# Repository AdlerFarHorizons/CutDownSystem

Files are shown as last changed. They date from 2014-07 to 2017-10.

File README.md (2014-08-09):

CutDownSystem
=============

Summary
-------
This is an arduino-based system for separating a high-altitude balloon from its payload under
pre-determined conditions.

Documentation
------------
The documentation available for this system is included in the /docs directory.

Software
--------
In order to run this system, two Arduino boards are required, assembled according to the SCHEMATIC
file. They are pre-programmed; to modify this system, a computer running Arduino IDE is required.
To program the Arduinos, upload new code as specified through the Arduino IDE to the CutDownBase.
The CutDownBase will wirelessly transfer pertinent code to the CutDownRemote.

Licensing
--------
Please see the file named LICENSE.

Contacts
--------

Lou Nigra
Adler Planetarium - Far Horizons Lab

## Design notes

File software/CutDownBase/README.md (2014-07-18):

BaseModule

v3.00 Updated to work with a Copernicus II's GPS readings. This version uses altitude
for its cutdown check, but the position (coordinates) is also available.
SD card logging capability added. Note that GPS connections changed for new software
serial pin assignments for XBee shield SD card compatibility.

v1.10 Updated to avoid conflicts with other Serial messages and added support for
putting the XBee to sleep until near cutdown time.

Brendan Batliner and Milan Shah
Illinois Mathematics and Science Academy - SIR Program

Notes on SD card integration - LN
REF: http://arduino.cc/en/Main/ArduinoWirelessShield
  
  The Wireless shield hardwires Arduino pin 4 to the on-board
  SD card slot's SPI chip select (CS), so it can't be used as
  a Software Serial pin as in the TinyGPS example. Also
  The Arduino's MOSI, MISI and CLK pins (11,12 and 13) are used
  by the SD library and even if not used for SD CS, the default
  CS pin 10 must be programmed as an output.
  
  So, software serial can be assigned to 5 and 6 safely.
  
  TESTING:
  Can be tested without remote cutdown and remote programmer units:
  1. Remove XBee from XBee shield so Arduino USB I/O will work
  2. Provide input via a single monitor line entry emulating the
     remote inputs, for example:
     X90,100000,300,41.1000322,-87.9167100
     This yields: Remote cutdown time (deadman): 90 minutes
                  Cutdown altitude: 100,000 feet
                  Cutdown range: 300 miles
                  Launch Lat/Lon: Koerner Aviation

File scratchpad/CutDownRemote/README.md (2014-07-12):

<h3>CutDownRemote</h3>
<h4>Code for Remote Cutdown Module</h4>
Placed between parachute and ballooon tether, the Remote Cutdown Module cuts connection to the tether when certain conditions are met as determined by the Base Cutdown Module and triggered by wireless sigal. The remote module has a timer pre-set at launch that will trigger the cutdown if other criteria are not met or fail to get a trigger to the remote.

<h4>Revision History</h4>

Placed under CVS at V5.00

V5.00 Adds support for the BaseModule's GPS functions. It will ask
the user about the maximum altitude of the flight and supply this to
the BaseModule.

V3.11 Now No longer Sends the Query 'Q'

V3.01 Now avoids character conflict with base module, to allow the use of a third Xbee to program both the base module and Cutdown arduino

V3.00 Some fixes for high XBee current and workarounds for lack of single point setup control in alpha base station.
- Put XBee to sleep when not needed. Required hardware change.
- Use variable LED flash count to signal ready for input from base allows setup without terminal connection.
- Programming mode until cutter cap is nearly charged.

<h4>Credits</h4>

Lou Nigra
Adler Planetarium - Far Horizons

Brendan Batliner and Milan Shah
Illinois Mathematics and Science Academy - SIR Program

<h4>Controls</h4>

- Raw voltage tied to charger ON switch
- Programming mode when serial port is connected via 3.3V FTDI and XBee removed
- Timer activate/de-activate momentary contact switch (no longer used)

<h4>Indicators</h4>

- LED no blink: Charging => Programming mode inhibited.
- LED fast blink: Active => Timer is counting down.
- LED long Off: Standby => Waiting for programming window to open.
- LED single three flashes: Programming mode => Window open for "non-D"
                            input to enter programming mode.

The following sequence follows if a non-D character is entered while
the window is open:

- LED single six flashes: Parameter prompt: => Ready for parameter entry.
- LED three flashes: Confirmation: => Ready for y or n

<h4>State Machine</h4>
- standby -> WAITFORCHARGE
- WAITFORCHARGE
-   -> GETTTY
- GETTTY
-   (timeout) -> SLEEP
-   (entries) -> active -> SLEEP
- SLEEP
-   standby? > TTY
-   active?  -> timerUpdate

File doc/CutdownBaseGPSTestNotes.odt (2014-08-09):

Cutdown Base/GPS Notes

4/23/14 - Clear Day

Best feedback from GPS when separated from the payload by at least 6 inches, or when left on top of the mini maglite black box inside the payload or at least separated from the cut-down arduino.

Insulation on top of the payload did not appear have any effect on GPS when left separate from the arduino. Results were less consistent when GPS placed on top of the payload cover.

When outside and on top of the payload, best results were on the corners that were furthest from the cut-down arduino.

Also, results seemed to vary depending on which side of the payload the wire protrudes from when GPS is placed on top.

Possible factors for varying results: smaller number of satellites in range (however we have no way of knowing when this is the case, as we do not have a display for that variable) Also the material of the foam insulation of the payload could affect/disturb the RF performance of the device. I will continue tests tomorrow, so as to make sure the results of today are not anomalous.

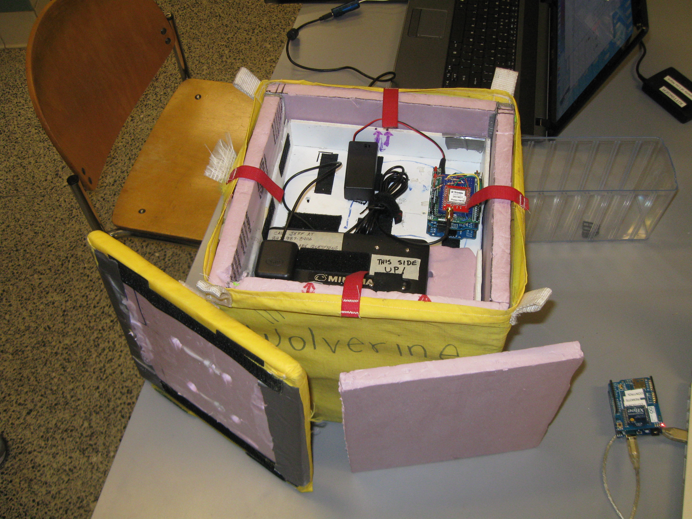
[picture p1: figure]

Illustration 1: Payload with top removed

4/24/14 - Overcast Day

Very poor feedback from GPS when placed anywhere on or in the box.

Best results when GPS receiver placed off of the payload all together, but even then the results are not 100%. May go for a couple of seconds or more before it picks the signal back up.

Tried using just the top of payload and took out extra layer of insulation, seemed to work for a few seconds, then nothing regardless of the corner it was on.

4/29/14 - Mostly Overcast Day

Worked fine with spacer and lid with antenna mounted near corner on maglite case. Also worked at other side of case. Box set on south part of elevator platform with antenna facing antenna doors.

Turned maglite GPS on with spacer removed at 16:28.

Replaced spacer at about 16:31.

Lost data from CutDownBase at 16:34:11 UTC. Not sure if battery died, or just stopped getting fixes.

NOTE: According to the log, the Maglite GPS got no fixes until 10 seconds after CutDownBase GPS stopped getting fixes.

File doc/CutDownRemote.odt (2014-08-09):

CutDownRemote

Lou Nigra
Adler Planetarium – Far Horizons

Rachael Affenit
Illinois Institute of Technology

Kelli W.

Summary:

The CutDownRemote will receive information and new code via Xbee from the CutDownBase. Timer and all other variables can be set remotely via CutDownBase.

The CutDownRemote contains a timer, which can also be changed via the button interface.

When the CutDownRemote capacitors are fully charged (~4.5 volts), charging will cease until charge level has dropped a designated percent below the target value, then resume.

Indicators:

- LED (Charge)
  - Off >> Not yet charged
  - On >> Fully charged
- LED (Timer)
  - Off >> Timer inactive
  - Flashing every 1 second >> Timer active and counting down
- LED (Set Mode)
  - Off >> Not in “Set” Mode
  - On >> Inside “Set” Mode (hold down “Set” switch to deactivate)
- Row of LEDs (Current Variable on Display Lit)
  - Time >> “Timer” LED Lit
  - % Charge on Battery >> “Batt” LED Lit
  - % Charge on Capacitors >> “Cap” LED Lit

Controls:

- Start/Stop Toggle Switch (Timer)
  - Start Timer: Push in switch
  - Stop Timer: Push in and release switch
    - Timer LED turns off
- Set Toggle Switch
  - Enter Set Mode: Push in switch
  - Done Setting Time: Push in and release switch
- Up/Down Momentary Contact Switches (Change time in Set mode)
  - Press up/down buttons to set time
  - Buttons change time by 1 minute in each direction
- Change Variable Momentary Contact Switch
  - Scroll through variables values on display: Press switch (reacts on touch)

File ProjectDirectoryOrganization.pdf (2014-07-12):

## Far Horizons Project Directory Organization

Rev 2.0 August 25, 2013 Lou Nigra
Document Formats
Routine documentation should be in one of the following open formats compatible with free and open source viewers/editors such as OpenOffice, LibreOffice and web browsers, as well as MS Office:

Text-based:
.txt .rtf .docx .html .pdf

Spreadsheet:
.xlsx

Presentation:
.pptx

NOTE ON FILE SIZE:

With figures added to documents, file size can get into the several MB and higher (especially with presentations). Avoid making any document that will be put up in the public domain larger than it has to be. A rough limit might be 1 or 2 MB. You can take forever optimizing this, but just paying attention to it by taking the time to crop and resize images to the actual size needed for real-life viewing can pay off dramatically. Hyperlinks, of course are not a problem.

This DOES NOT apply to internal documents such as presentations (go crazy on those!) and reports. If we publish these to the web after the fact, we can take the time to make a lightweight version appropriate for the web.

The naming of things...

Code Content:
For a given programming language, please google "naming conventions" for code written in that language (e.g., "arduino naming conventions") and try to follow this as best you can in the code. In any case, be self-consistent.

Code Source Files:
Source file names sometimes have conventions as well, but generally not.

Other Files:
For non-code files that you create, the actual name portion of file names should use "CamelCase" convention, where each descriptive word is capitalized rather than separated by spaces or underscores or the like.

After the name part, which should be generic and descriptive, you should add something to distinguish it from other files of the same basic name separating it from the name with a dash. Where that needs further separation, we use underscores. Finally, there's the document suffix that is always separated by a period. That should be the ONLY period.

Every document should have a generic descriptive name and files of the same type should be distinguished from each other by a sequence number, a version number or a date:

a) A simple sequence number: SomeDescriptiveName-34.jpg
b) A version number with two levels (no more, no less): SomeOtherName-V3_12.docx
c) A date: OneReallyAmazingVideo-2013_06_01.mov NOTE: the format is NOT the American “dmy” convention, but the sensible standard the rest of the world uses in its reversed form: yyyy_mm_dd. Add "_ss" if seconds are necessary.
d) A person's initials can be optionally added to any filename: TheBestDesignEver-V943_1_LN.docx

Directories:
Preferably a simple, single-word lowercase name if it's a category like the directories described below. If it has to be more specific, like a directory for a particular program (as with Arduino sketches) then use CamelCase.
The placing of things...

The project directory is organized hierarchically. In the descriptions below, "./" represents the project directory and directories have a trailing "/", while files don't.

./data/
Raw(-ish) data that is large and doesn't have much meaning on its own as documentation, such as raw and high resolution images that need to be kept, files of collected data samples, etc. Organize this into folders if you can and as you see fit.

This directory is will not be tracked on GitHub.

./doc
Documentation that relates to the system design rather than hardware or software design material. An example would might be project design specifications, notes and analysis.

./hardware/
Source files required to re-create and build the hardware design if the project involves hardware design. That would include Eagle schematics and board layouts, mechanical sketches, drawings, etc. The project might include distinct pieces or "modules" that would lend themselves to having separate sub-directories. If there are a lot of files for a single module, you might consider further organizing it into subdirectories such as 'electrical' and 'mechanical' for example.

./hardware/doc/
Hardware-specific design notes, analysis and documentation.

./scratchpad/
This is for any material (programs, schematics, notes, analysis, etc.) that isn't part of the actual design or is still a work in progress. For instance, when you first start on a project, you might try some experimental things to get started or maybe check out some alternative approach to some aspect along the way.

./software/
Source code for any software developed in the project. If there are separate distinct software programs.

.software/doc/

Software-specific design notes, analysis and documentation.

./doc/

Project-level notes, analysis and documentation.

./reference/

Reference material for the project, organized into subdirectories if necessary. This is for things like documents from online sources, designs and code we borrowed from someone else, etc.

The "references.txt" file describes where you got this material. It can also include a description of aother things you used even if there are no associated files, for example, a description/acknowledgment of someone outside of Far Horizons who made a significant contribution. This might have been help with troubleshooting, giving advice or conversations having an impact on the project.

Nothing in this directory except the "references.txt" file should be modified in any way.

./ProjectDirectoryOrganization.pdf

This file.

./README.md

This is visible on the GitHub project page. See the file for a description what should be in it.

./.git/

This is the directory used by git. DO NOT modify it or any of its contents.

./.gitignore

This is a hidden file that tells the git program which directories and file types to ignore in tracking with the GitHub repository. They won't get uploaded to GitHub and are not tracked for changes.

DO NOT edit this file unless you are absolutely sure of what you are doing. Consult with a Far Horizons Engineer if you think files are being suppressed that shouldn't be or if you think some file types or directories should be added to the list.

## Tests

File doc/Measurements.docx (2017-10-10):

The Circuit Layout

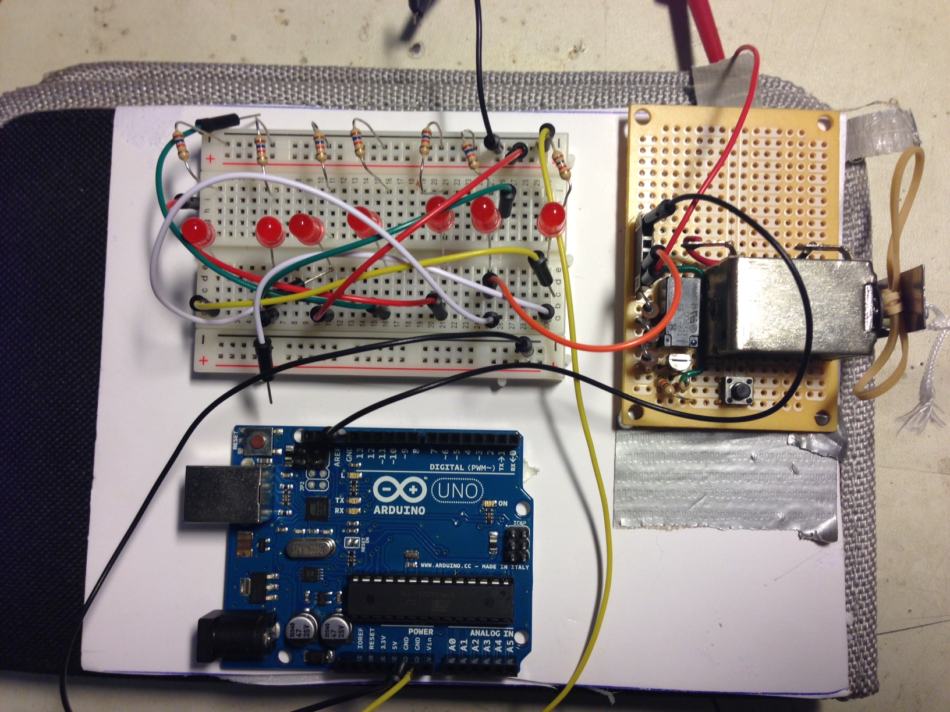
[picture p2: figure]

Some distance displacement for spring in order to get the maximum Force.

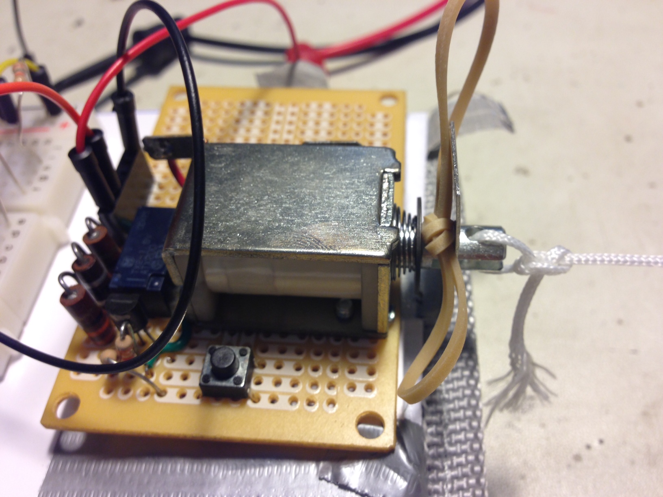
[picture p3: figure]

Experiment Set Up

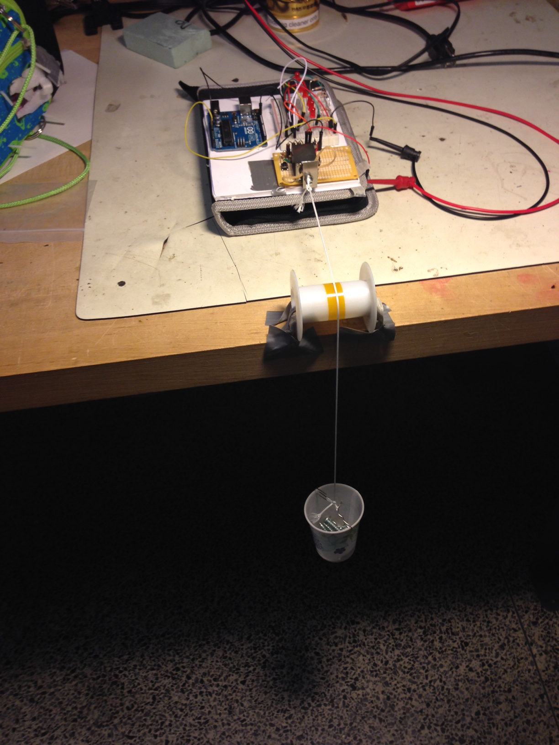
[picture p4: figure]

February 21st, 2015

Today, I have tried to verify experimentally if properties of solenoids F0411A and G0403A correspond to their properties from Data Sheet.

In order to find these properties, I attached weights to the solenoids’ shafts and tested if they could hold the weight. The weights were attached vertically down from the solenoids’ shafts.

The shat itself weights = 8 grams

F0411A – Pontiac Coil (PL012DC) → Continuous

This solenoid has a continuous pull. According to the data sheet, it should have a sealed force of 41 oz., which is 1162 grams.

Experimentally Tested:

1158 g (weight) + 8 g (shaft)= 1166 g → did hold

1174 g (weight) + 8 g (shaft)= 1182 g → did not hold

As a result, experimentally results are very close to those from data sheet specifications.

G0403A – Pontiac Coil → Pulse

According to the data sheet, this solenoid should have a latched force of 37 oz., which is 1049 grams.

Experimentally Tested:

1628 g (weight) +8 g (shaft) = 1636 g → held for 20 seconds and it could more

1702 g (weight) +8 g (shaft) = 1710 g → held for 20 seconds and it could more

1769 g (weight) +8 g (shaft) = 1777 g → held for 18 seconds and it fell down

As a result, the tested results are higher than those from data sheet. Therefore, we might use this solenoid for our upcoming experiment.

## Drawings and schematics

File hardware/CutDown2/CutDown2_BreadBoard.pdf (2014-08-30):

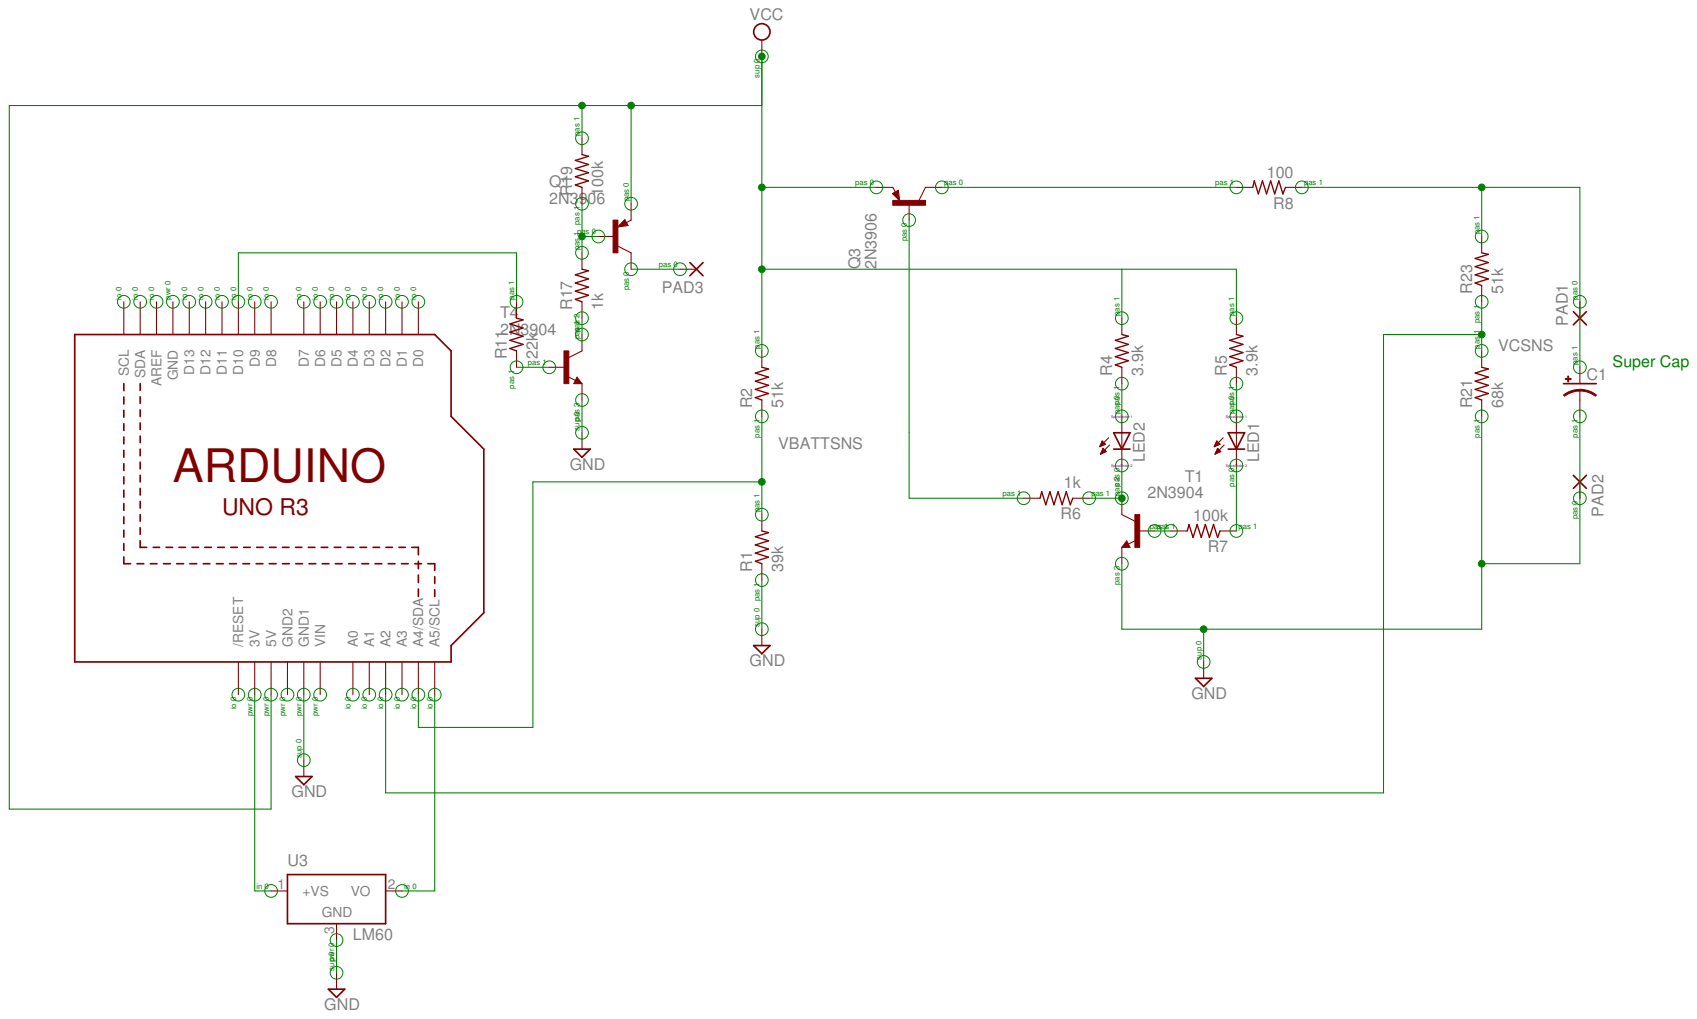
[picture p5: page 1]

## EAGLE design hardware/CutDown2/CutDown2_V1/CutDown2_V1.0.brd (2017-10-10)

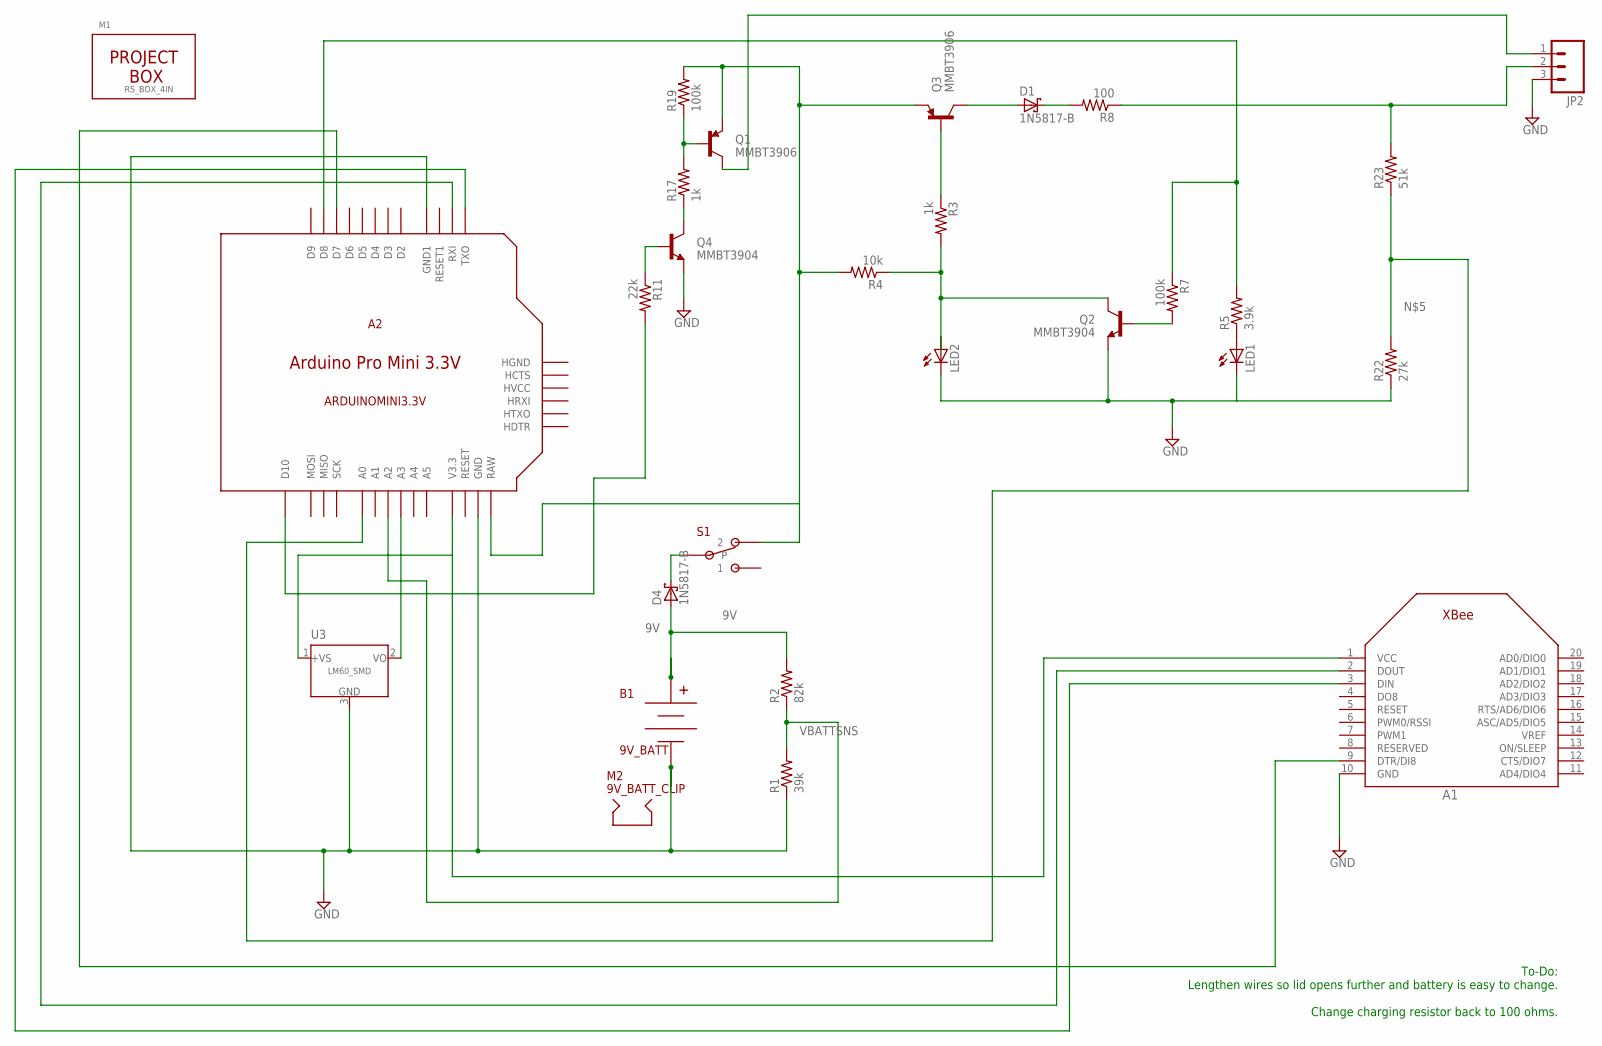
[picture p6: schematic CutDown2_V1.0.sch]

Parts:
A1: XBEE
A2: ARDUINOMINI3.3V
B1: 9V_BATT; KEYSTONE_593_594
D1, D4: 1N5817-B; DO41-7.6
JP2: M03POLAR_LOCK; MOLEX-1X3_LOCK
LED1, LED2: LED_ELD260; LED_LD260
M1: RS_BOX_4IN; RS_BOX_OUTLINE_4IN
M2: 9V_BATT_CLIP; KEYSTONE_9V_CLIP_H
Q1, Q3: MMBT3906; SOT23
Q2, Q4: MMBT3904; SOT23
R1: 39k; R0805
R2: 82k; R0805
R3, R17: 1k; R0805
R4: 10k; R0805
R5: 3.9k; R0805
R7, R19: 100k; R0805
R8: 100; R0805
R11: 22k; R0805
R22: 27k; R0805
R23: 51k; R0805
S1: APEM_SPDT_25000NH
U3: LM60_SMD; SOT23-3

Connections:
9V: B1.P$1 (V+), B1.P$2 (V+), B1.P$3 (V+), D4.A, R2.2
GND: A1.10 (GND), A2.P$9 (GND1), A2.P$20 (GND), B1.P$4 (V-), B1.P$5 (V-), B1.P$6 (V-), JP2.3, LED1.K (C), LED2.K (C), Q2.2 (E), Q4.2 (E), R1.1, R22.1, U3.3 (GND)
unnamed: Q3.1 (B), R3.1
unnamed: D1.A, Q3.3 (C)
unnamed: A2.P$2 (D8), R5.2, R7.1
unnamed: LED1.A, R5.1
unnamed: A2.P$26 (A0), R22.2, R23.1
unnamed: D1.C, R8.2
unnamed: LED2.A, Q2.3 (C), R3.2, R4.1
unnamed: A1.2 (DOUT), A2.P$11 (RXI)
unnamed: A2.P$23 (A3), U3.2 (VO)
unnamed: A1.3 (DIN), A2.P$12 (TXO)
unnamed: D4.C, S1.P$3
unnamed: Q2.1 (B), R7.2
unnamed: Q4.3 (C), R17.1
unnamed: Q1.1 (B), R17.2, R19.1
unnamed: JP2.1, Q1.3 (C)
unnamed: A2.P$30 (D10), R11.2
unnamed: Q4.1 (B), R11.1
unnamed: JP2.2, R8.1, R23.2
unnamed: A2.P$19 (RAW), Q1.2 (E), Q3.2 (E), R4.2, R19.2, S1.P$2 (2)
VBATTSNS: A2.P$24 (A2), R1.2, R2.1
VCC: A1.1 (VCC), A2.P$22 (V3.3), U3.1 (+VS)
VCSNS: A1.9 (DTR/DI8), A2.P$3 (D7)

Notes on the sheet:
To-Do: Lengthen wires so lid opens further and battery is easy to change. Change charging resistor back to 100 ohms.

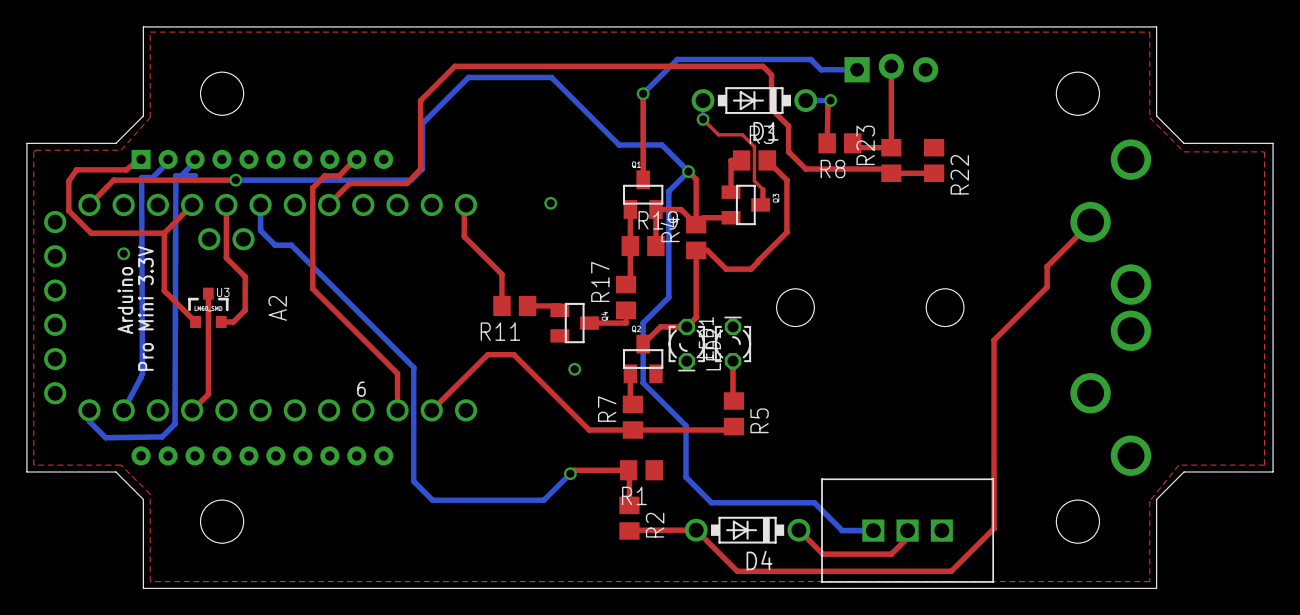
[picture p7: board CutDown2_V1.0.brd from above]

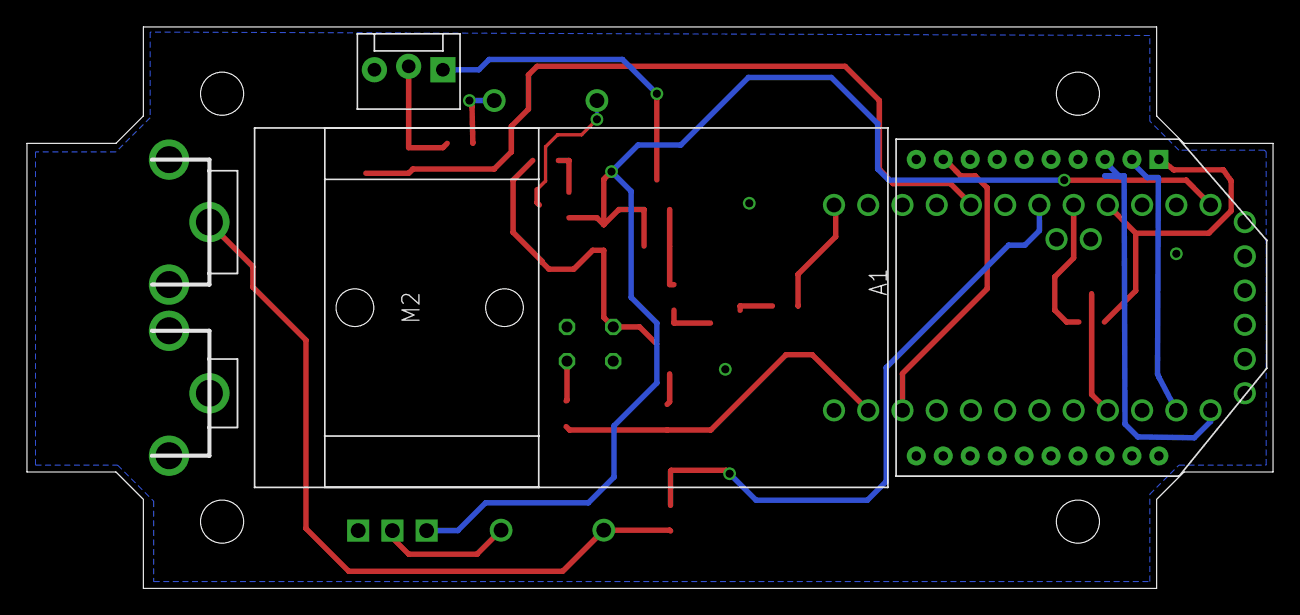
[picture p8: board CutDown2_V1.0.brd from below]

Board: 2 copper layers, 92.5 x 41.7 mm, 28 parts (4 on the bottom side), 24 nets.

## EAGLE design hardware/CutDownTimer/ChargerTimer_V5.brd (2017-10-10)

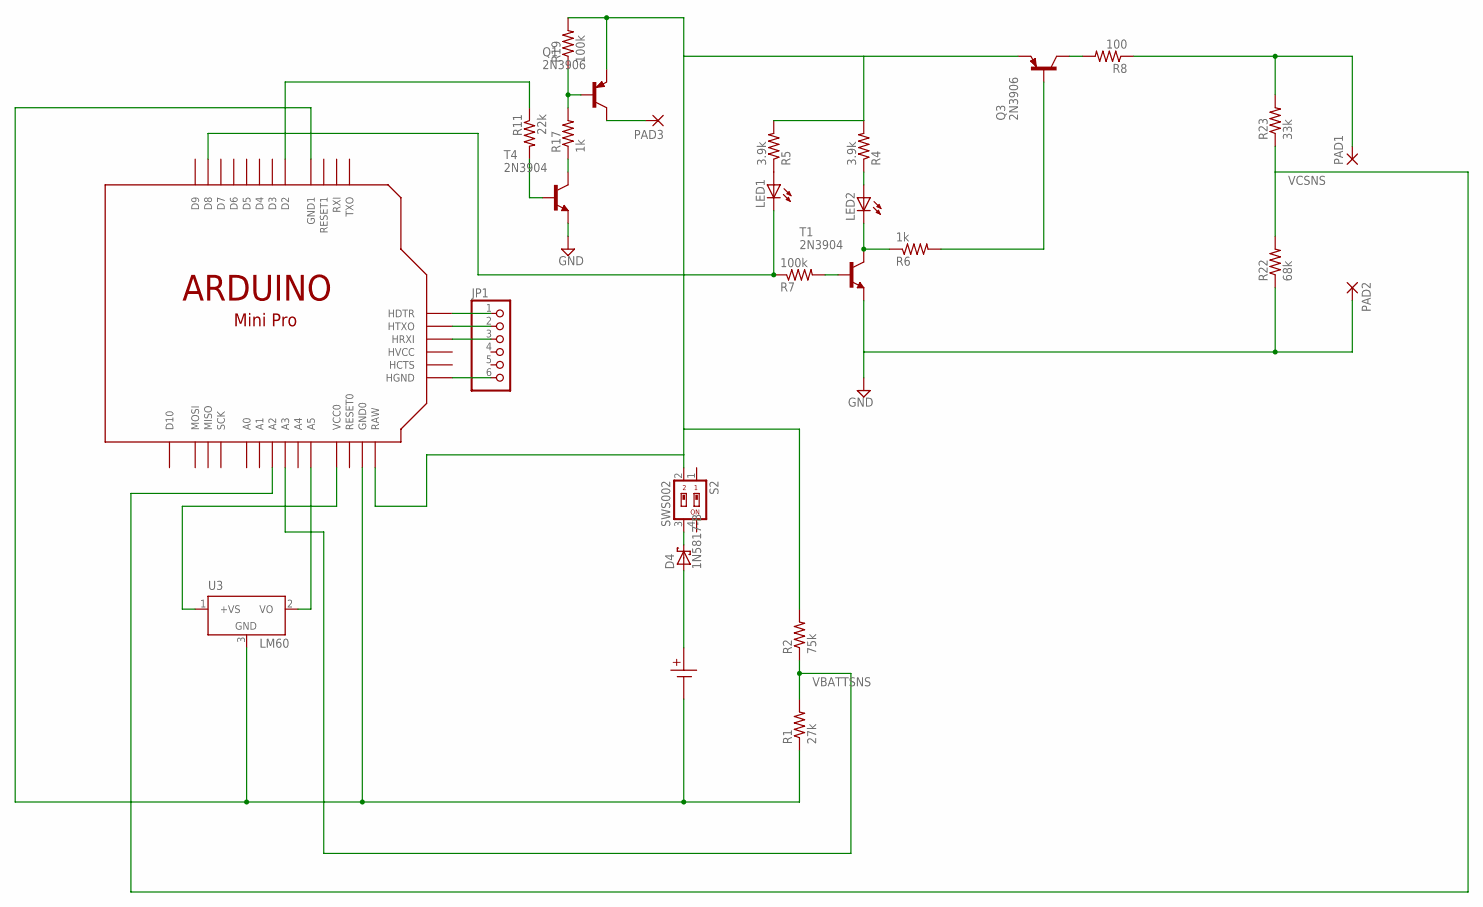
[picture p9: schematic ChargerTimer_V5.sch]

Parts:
D4: 1N5817-B; DO41-7.6
JP1: PINHD-1X6; 1X06
LED1, LED2: LED_ELD260; LED_LD260
PAD1, PAD2, PAD3: 2,15/1,0
Q1, Q3: 2N3906; TO92
R1: 27k; 0207/7
R2: 75k; 0207/7
R4, R5: 3.9k; 0207/7
R6, R17: 1k; 0207/7
R7, R19: 100k; 0207/7
R8: 100; 0207/7
R11: 22k; 0207/7
R22: 68k; 0207/7
R23: 33k; 0207/7
S2: SWS002; SMS-002
T1, T4: 2N3904; TO92
U3: LM60; TO92
U$1: BH1000G
U$4: ARDUINOMINI

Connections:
GND: T1.3 (E), T4.3 (E)
unnamed: Q3.1 (C), R8.2
unnamed: LED1.K (C), R7.1, U$4.P$2 (D8)
unnamed: LED1.A, R5.1
unnamed: LED2.A, R4.1
unnamed: LED2.K (C), R6.1, T1.1 (C)
unnamed: Q3.2 (B), R6.2
unnamed: D4.C, S2.3
unnamed: PAD2.1, R22.1
unnamed: R11.1, U$4.P$8 (D2)
unnamed: Q1.3 (E), Q3.3 (E), R2.2, R4.2, R5.2, R19.2, S2.2, U$4.P$19 (RAW)
unnamed: R7.2, T1.2 (B)
unnamed: R17.1, T4.1 (C)
unnamed: Q1.2 (B), R17.2, R19.1
unnamed: PAD3.1, Q1.1 (C)
unnamed: U3.2 (VO), U$4.P$35 (A5)
unnamed: JP1.1, U$4.P$13 (HDTR)
unnamed: U3.1 (+VS), U$4.P$22 (VCC0)
unnamed: R11.2, T4.2 (B)
unnamed: JP1.2, U$4.P$14 (HTXO)
unnamed: R1.1, U3.3 (GND), U$1.NEG$2 (P2), U$4.P$9 (GND1), U$4.P$20 (GND0)
unnamed: D4.A, U$1.POS$1 (P1)
unnamed: JP1.3, U$4.P$15 (HRXI)
unnamed: JP1.6, U$4.P$18 (HGND)
unnamed: PAD1.1, R8.1, R23.2
VBATTSNS: R1.2, R2.1, U$4.P$23 (A3)
VCSNS: R22.2, R23.1, U$4.P$24 (A2)

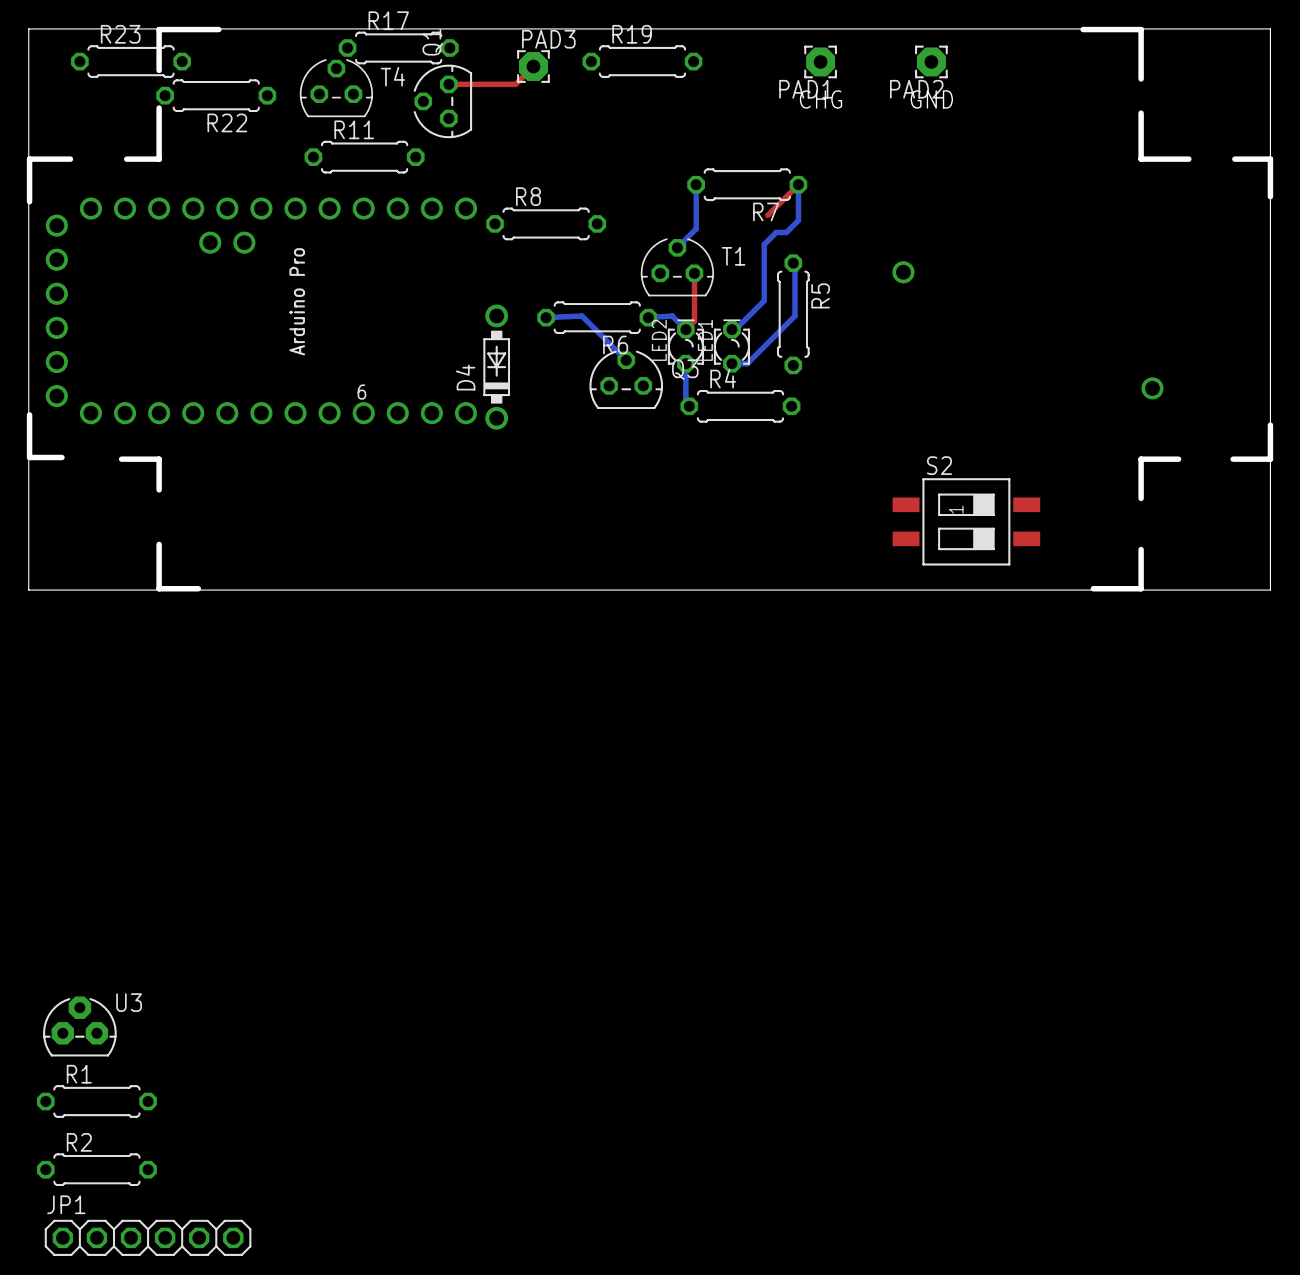
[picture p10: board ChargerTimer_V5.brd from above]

Board: 2 copper layers, 92.5 x 41.8 mm, 27 parts (1 on the bottom side), 27 nets.

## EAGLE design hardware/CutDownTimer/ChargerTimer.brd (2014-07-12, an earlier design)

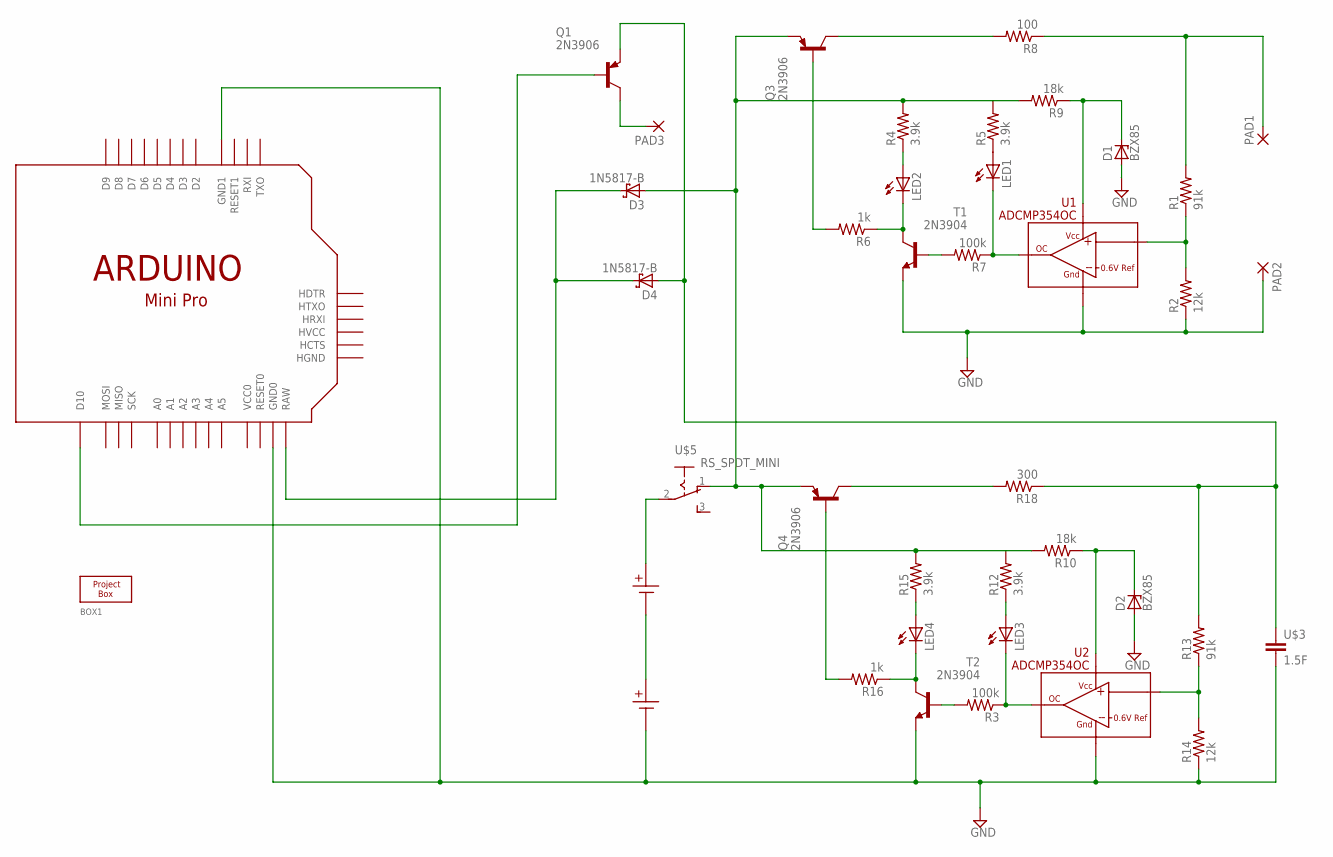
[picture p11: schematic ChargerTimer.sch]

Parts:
BOX1: RS_BOX_4IN; RS_BOX_OUTLINE_4IN
D1, D2: BZX85; DO41Z10
D3, D4: 1N5817-B; DO41-7.6
LED1, LED2, LED3, LED4: LED_ELD260; LED_LD260
PAD1, PAD2, PAD3: 2,15/1,0
Q1, Q3, Q4: 2N3906; TO92
R1, R13: 91k; 0207/7
R2, R14: 12k; 0207/7
R3, R7: 100k; 0207/7
R4, R5, R12, R15: 3.9k; 0207/7
R6, R16: 1k; 0207/7
R8: 100; 0207/7
R9, R10: 18k; 0207/7
R18: 300; 0207/7
T1, T2: 2N3904; TO92
U1, U2: ADCMP354OC; ADCMP35X
U$1, U$2: BH1000G
U$3: 1.5F; SUPERCAP1.0/0.85H
U$4: ARDUINOMINI
U$5: RS_SPDT_MINI

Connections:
GND: D1.A, D2.A, PAD2.1, R2.1, R14.1, T1.3 (E), T2.3 (E), U1.P2 (GND), U2.P2 (GND), U$2.NEG$2 (P2), U$3.P$2 (2), U$4.P$9 (GND1), U$4.P$20 (GND0)
unnamed: R1.1, R2.2, U1.P1 (IN)
unnamed: Q3.1 (C), R8.2
unnamed: LED1.K (C), R7.1, U1.P3 (OUT)
unnamed: LED1.A, R5.1
unnamed: LED2.A, R4.1
unnamed: LED2.K (C), R6.1, T1.1 (C)
unnamed: Q3.2 (B), R6.2
unnamed: PAD1.1, R1.2, R8.1
unnamed: R3.2, T2.2 (B)
unnamed: D4.A, Q1.3 (E), R13.2, R18.1, U$3.P$1 (1)
unnamed: U$1.POS$1 (P1), U$5.2
unnamed: U$1.NEG$2 (P2), U$2.POS$1 (P1)
unnamed: R7.2, T1.2 (B)
unnamed: D1.C, R9.1, U1.P4 (VCC)
unnamed: D2.C, R10.1, U2.P4 (VCC)
unnamed: R13.1, R14.2, U2.P1 (IN)
unnamed: LED3.K (C), R3.1, U2.P3 (OUT)
unnamed: LED3.A, R12.1
unnamed: LED4.A, R15.1
unnamed: LED4.K (C), R16.1, T2.1 (C)
unnamed: Q4.2 (B), R16.2
unnamed: Q4.1 (C), R18.2
unnamed: D3.A, Q3.3 (E), Q4.3 (E), R4.2, R5.2, R9.2, R10.2, R12.2, R15.2, U$5.1 (O)
unnamed: PAD3.1, Q1.1 (C)
unnamed: D3.C, D4.C, U$4.P$19 (RAW)
unnamed: Q1.2 (B), U$4.P$30 (D10)

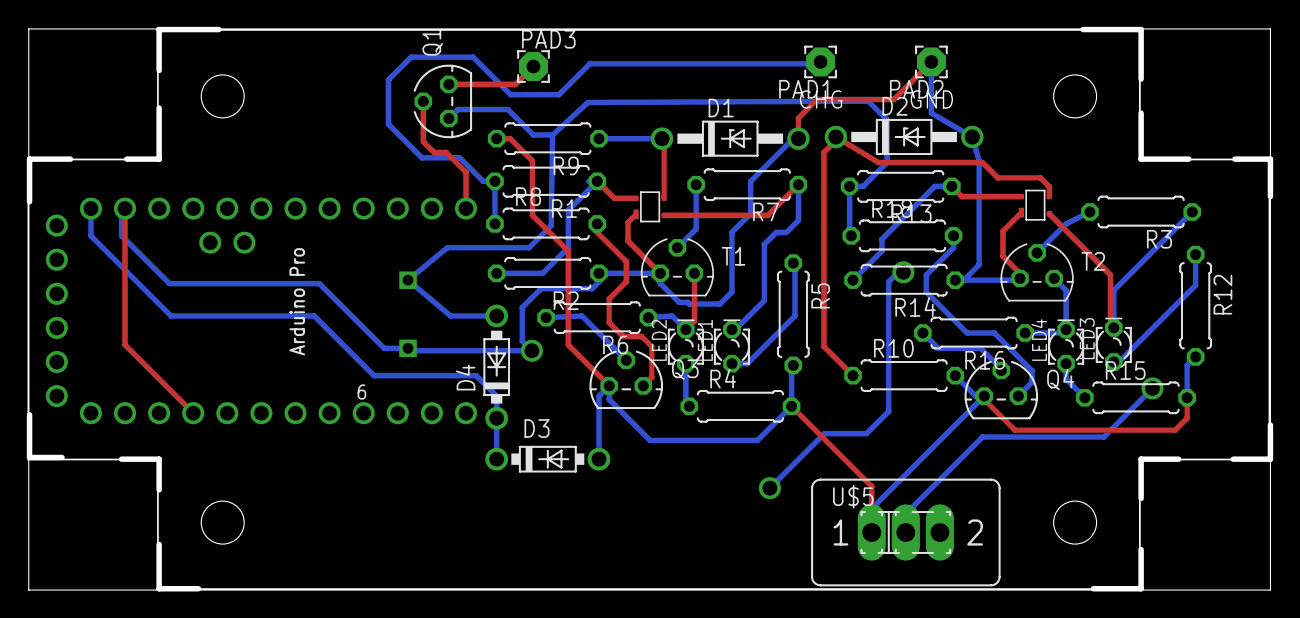
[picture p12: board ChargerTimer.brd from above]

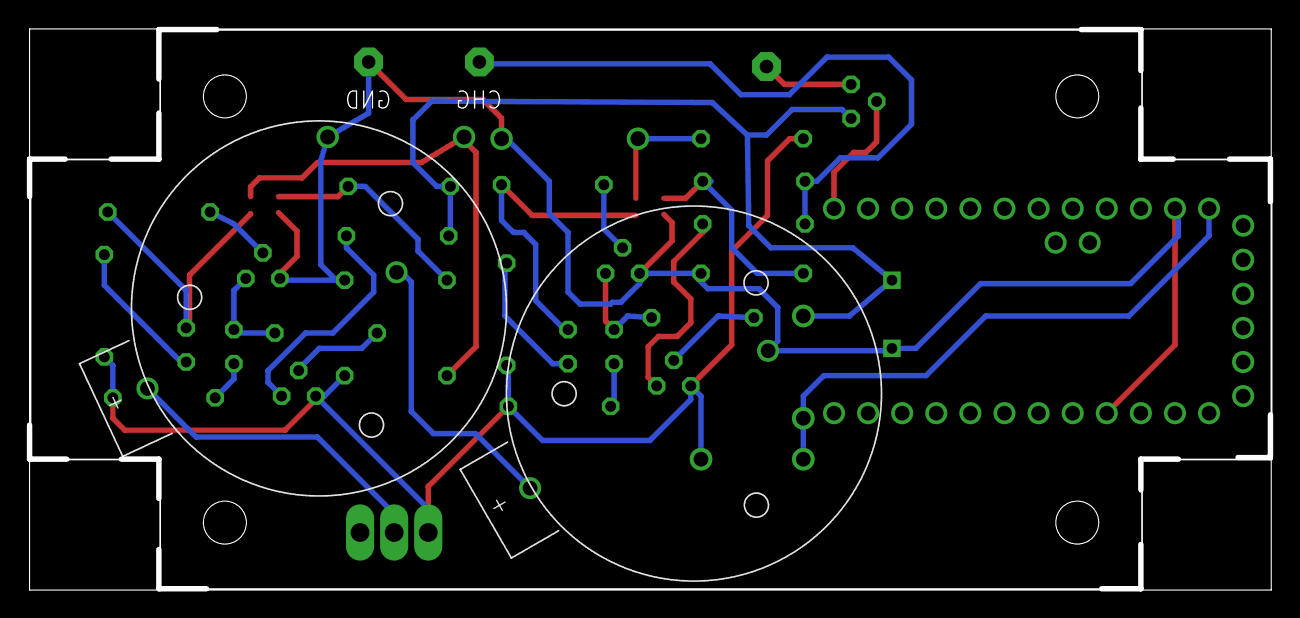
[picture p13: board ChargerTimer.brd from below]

Board: 2 copper layers, 92.5 x 41.8 mm, 40 parts (3 on the bottom side), 27 nets.

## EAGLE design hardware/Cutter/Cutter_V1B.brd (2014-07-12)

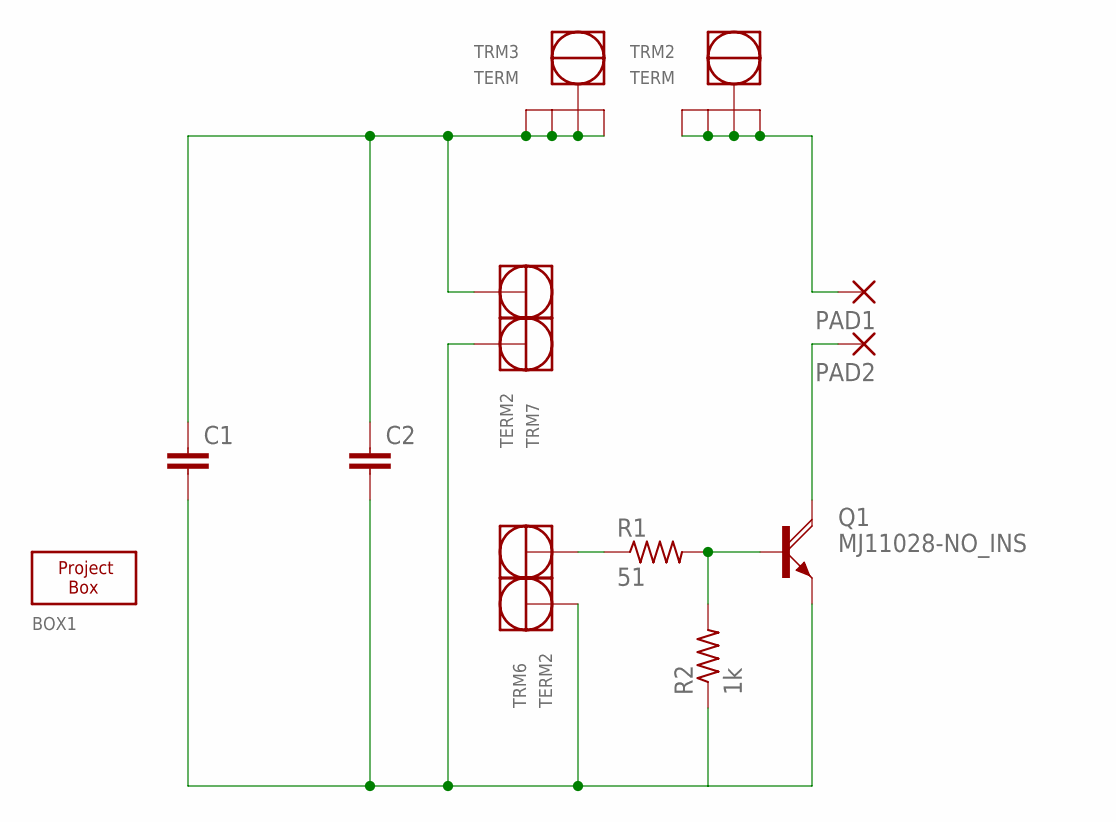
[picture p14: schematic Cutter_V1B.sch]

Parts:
BOX1: RS_BOX_3IN; RS_BOX_OUTLINE_3IN
C1, C2: C1400X850; SUPERCAP1.4/0.85H
PAD1, PAD2: 2,15/1,0
Q1: MJ11028-NO_INS; TO-3-NO_INSULATOR
R1: 51; 0207/10
R2: 1k; 0207/10
TRM2, TRM3: TERM; SCREWTERM-300MILSQ
TRM6, TRM7: TERM2; SCREWTERMBLK-DUAL

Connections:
C: PAD2.1, Q1.C, Q1.C1 (C)
unnamed: C1.P$2 (2), C2.P$2 (2), Q1.E, R2.1, TRM6.P$1 (P1), TRM7.P$1 (P1)
unnamed: C1.P$1 (1), C2.P$1 (1), TRM3.P$1 (P1), TRM3.P$2 (P2), TRM3.P$3 (P3), TRM3.P$4 (P4), TRM7.P$2 (P2)
unnamed: PAD1.1, TRM2.P$1 (P1), TRM2.P$2 (P2), TRM2.P$3 (P3), TRM2.P$4 (P4)
unnamed: Q1.B, R1.2, R2.2
unnamed: R1.1, TRM6.P$2 (P2)

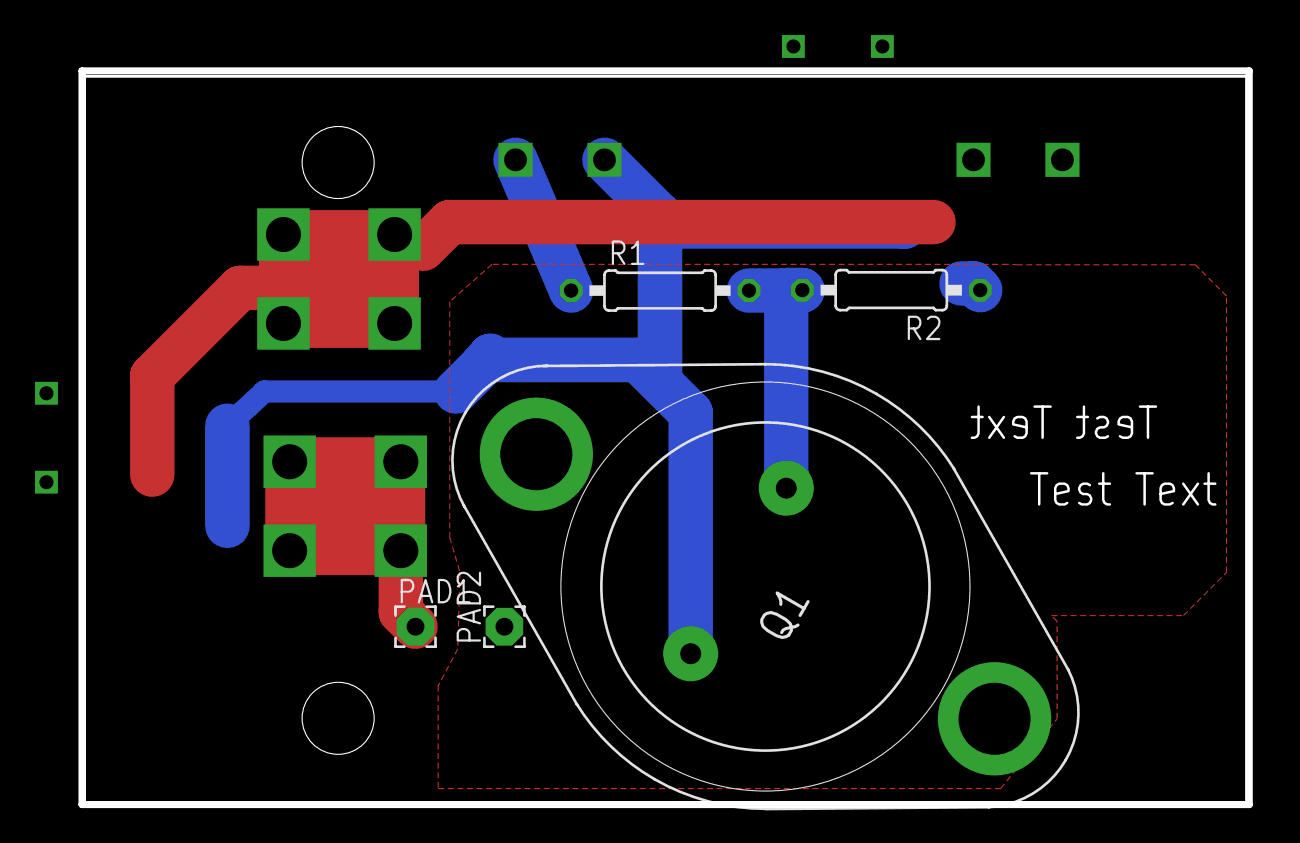
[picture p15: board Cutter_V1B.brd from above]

Board: 2 copper layers, 66.7 x 41.9 mm, 12 parts (0 on the bottom side), 6 nets.

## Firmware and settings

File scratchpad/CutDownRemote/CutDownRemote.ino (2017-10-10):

#include <EEPROM.h>
#include <MsTimer2.h>

// ADD HYSTERESIS: charge capacitors until certain percent above 4.5 volts,
// then allow to drain until same percent below, then resume charging.

// Analog Pin Assignments
int vCutCapPin = A0; // Reads voltage from capacitor
int vBattPin = A2;
int vTempPin = A3;

// Digital Pin Assignments
int cutPin = 2;
int setSwitchPin = 3;
int startSwitchPin = 4;
int upSwitchPin = 5;
int downSwitchPin = 6;
int chVarSwitchPin = 7;
int chargeCap = 8; // Set to LOW to charge capacitor

// Charge Constants
float vRefStop = 4.4;
float vRefStart = 4.1;
float vCC = 3.3;
// define variable that keep track where the threshold is
float vThreshold = 4.1;
//float vBattRange = vRef * 4.092;
//float vCutCapRange = vRef * 2.0;
//float vBackupCapRange = vRef * 2.0;

// EEPROM Constants
float timeOhFactor = 0.1213; // 0.0333; // Empirical with 3 second waitTime
int maxEepromAddr = 1023; // ATMega328
String dataValues = "2*(T+75)(C), vB*20(V), vC*20(V), Cut";

// Cutdown variables
int cutDelayMins; // Time until drop
boolean isCut; // Line has been cut

// Wait time variables
int waitTime = 30000;
int ledFlashTime;

// Sample variables
int sampleCount;
int sampleNum;
int sampleTime;

// User defined variables
int varnum = 1;

// Charge variables
float vCharged;
float vCutCap;
float vBatt;
boolean isCharged;
boolean chgEnable;

// Sensor variables
int dataSampleInterval;
int sensType;

// Activity variables
boolean active;

// Necessary for EEPROM
int eepromAddr;

void setup()
{
  // Switches & Cut Pin
  pinMode(cutPin, OUTPUT);
  pinMode(setSwitchPin, INPUT_PULLUP );
  pinMode(startSwitchPin, INPUT_PULLUP);
  pinMode(upSwitchPin, INPUT_PULLUP);
  pinMode(downSwitchPin, INPUT_PULLUP);
  pinMode(chVarSwitchPin, INPUT_PULLUP);
  pinMode(chargeCap, OUTPUT);
  
  /*
  // LED Setup
  pinMode(LEDPinTime, OUTPUT);
  pinMode(LEDPinBatt, OUTPUT);
  pinMode(LEDPinCap, OUTPUT);
  pinMode(LEDPinMode, OUTPUT);
  pinMode(LEDPinTimer, OUTPUT);
  pinMode(LEDPinCharge, OUTPUT);
  */
  
  chgEnable = true;
  activateCut( false );
  isCut = false;
  setTimerLED( false );
  sensType = 0; // LM60
  sampleTime = 60; // ms
  float temp = ( 1000.0 * sampleTime ) / ( 1.0 * waitTime );
  sampleCount = (int)( 0.5 + temp);
  ledFlashTime = 10; // ms
  vCharged = 4.4; // When used for testing purposes set this to 0.0

  active = false;
  cutDelayMins = 0;
  sampleNum = 1;
  digitalWrite(chargeCap,HIGH); // default is not charging
  
  Serial.begin(9600);
  Serial.flush();
  
  MsTimer2::set( waitTime, timesUp );
}

void loop()
{ 
  // Every 3 seconds as defined by MSTime2
  while( active );
  //detachInterrupt( 1 );
  
  vBatt = analogRead( vBattPin ) * ((39.0+51.0)/39.0)* vCC / 1024.0;
  vCutCap = (analogRead( vCutCapPin ) * 2.0 * vCC ) / 1024.0;
  Serial.print("vCutCap:");Serial.println( vCutCap );
  Serial.print("vBatt:");Serial.println( vBatt );
  Serial.print("vThreshold:");Serial.println( vThreshold );
  // If discharging and below voltage reference, start charging
  if(vCutCap > vThreshold)
  {
    vThreshold = vRefStart;
    digitalWrite(chargeCap,HIGH);
  }  
  if (vCutCap < vThreshold)
  {
    vThreshold = vRefStop;
    digitalWrite(chargeCap,LOW);
  }
  delay(1000);
  /*
  if (isCharged & (vCutCap <= vRefStart))
  {
    //digitalWrite(LEDPinCharge, LOW);
    waitForCharge();
  }
  
  // If switch is pressed (assuming active HIGH), allow time to be set
  while (getModeSwitch())
  {
    //digitalWrite(LEDPinMode, HIGH);
    
    // Display Current Timer Value
    Serial.print(cutDelayMins);
    
    if (digitalRead(upSwitchPin) == HIGH)
    {
      cutDelayMins += 1;
    }
    if (digitalRead(downSwitchPin) == HIGH)
    {
      cutDelayMins -= 1;
    }
  }
  
  if (digitalRead(chVarSwitchPin) == HIGH)
  {
    if(varnum == 3)
    {
      varnum = 1;
    }
    else
    {
      varnum += 1;
    }
  }
  
  if (varnum == 1)
  {
    //digitalWrite(LEDPinTime, HIGH);
    //digitalWrite(LEDPinBatt, LOW);
    //digitalWrite(LEDPinCap, LOW);
    
    // Display Time
    Serial.print(cutDelayMins);
  }
  
  if (varnum == 2)
  {
    //digitalWrite(LEDPinTime, LOW);
    //digitalWrite(LEDPinBatt, HIGH);
    //digitalWrite(LEDPinCap, LOW);
    
    // Display Percent Charge on Battery
    Serial.print("Batt Charge");
  }
  
  if (varnum == 3)
  {
    //digitalWrite(LEDPinTime, LOW);
    //digitalWrite(LEDPinBatt, LOW);
    //digitalWrite(LEDPinCap, HIGH);
    
    // Display Percent Charge on Capacitors
    Serial.print("Percent Cap Charge");
  }
  
  //digitalWrite(LEDPinMode, LOW);
  
  if ( digitalRead(startSwitchPin) == HIGH )
  {
    active = true;
    //digitalWrite(LEDPinTimer, HIGH);
    
    if ( cutDelayMins > 0 )
    {
      Serial.println("Timer is now active.");
      Serial.println("");
      Serial.flush();
      Serial.write('X');
      Serial.print(cutDelayMins);
      Serial.print(",");
      Serial.println( "Min, T(C), Vbat(V), Vcut(V), Cut");
      Serial.flush();
      eepromAddr = 1;
      EEPROM.write( 0, eepromAddr ); // Initial eeprom address
    }
    
    else
    {
      active = false;
    }
  }
  
  if ( digitalRead(startSwitchPin) == LOW )
  {
    active = false;
  }
  
  else
  {
    flashTimerLED( ledFlashTime, 1 );
    boolean tmp = cutdownReceived();
    
    if ( tmp && chgEnable )
    {
      activateCut( tmp );
      chgEnable = false; // This branch only once
      isCut = true;
      delay(100);
    }
    
    if (sampleNum >= sampleCount)
    {
      float temp = readTemp( vTempPin, 0 );
      vBatt = analogRead( vBattPin ) / 1024.0;       
      float vCutCap = analogRead( vCutCapPin ) / 1024.0;
      
      Serial.print( cutDelayMins );
      Serial.print( ", ");       
      Serial.print( temp );
      Serial.print( ", ");
      Serial.print( vBatt );
      Serial.print( ", ");
      Serial.print( vCutCap );
      Serial.print( ", ");
      Serial.println( tmp );
      Serial.flush();
      
      temp = 2.0 * ( temp + 75.0 ); // Shift temperature range
      // Constrain readings to byte values
      if ( temp > 255 )
      {
        temp = 255;
      }
      
      if ( temp < 0 ) temp = 0;
      {
        vBatt /= 0.05;
      }
      
      if ( vBatt > 255 )
      {
        vBatt = 255;
      }
      
      if ( vBatt < 0  )
      {
        vBatt = 0;
      }
      
      vCutCap /= 0.05;
      
      if ( vCutCap > 255 )
      {
        vCutCap = 255;
      }
      
      if ( vCutCap < 0  )
      {
        vCutCap = 0;
      }
      
      // EEPROM TIMER CODE
      // If out of eeprom, keep overwriting the last set of samples
      if ( eepromAddr > maxEepromAddr )
      {
        eepromAddr = ( maxEepromAddr - 3 );
      }
      EEPROM.write( eepromAddr, byte( temp ) );
      eepromAddr +=1;
      EEPROM.write( eepromAddr, byte( vBatt ) );
      eepromAddr +=1;
      EEPROM.write( eepromAddr, byte( vCutCap ) );
      eepromAddr +=1;
      EEPROM.write( eepromAddr, byte( isCut ) );
      EEPROM.write( 0, byte(eepromAddr) );
      eepromAddr += 1;
      sampleNum = 0;
    }
    
    sampleNum += 1;
  }
  
  Serial.flush();
  */ 
} // END OF VOID LOOP

// ACTIVATE CUTDOWN
void activateCut( boolean state )
{
  digitalWrite( cutPin, state );
}


// STOP TIMER
// Required for EEPROM timer
void timesUp()
{
  active = false;
}


// CUTDOWN CHECK
// Has the remote cutdown order ('C' byte) been recieved?
boolean cutdownReceived()
{
  boolean isReceived = false;
  for (int i = 0; i < 10; i++) 
  {
    if (Serial.available() > 0)
    {
      int incomingByte = Serial.read();
      if (incomingByte == 'C')
      {
        isReceived = true;
        Serial.println("Cutdown command received.");
        Serial.flush();
      }
    }
    delay(5);
  }
  return isReceived;
}


// SET TIMER LED
void setTimerLED( boolean state )
{
  if ( state )
  {
    //digitalWrite( LEDPinTimer, HIGH );
  }
  
  else
  {
    //digitalWrite( LEDPinTimer, LOW );
  }
}


// TIMER LED FLASH
void flashTimerLED( int flashTime, int numFlashes )
{
  for ( int i = 0 ; i < numFlashes ; i++ )
  {
    //digitalWrite( LEDPinTimer, HIGH );
    delay( flashTime );
    //digitalWrite( LEDPinTimer, LOW );
    delay(100);
  }
}


// GET TIMER ACTIVITY
boolean isActive()
{
  return( active );
}


// ACTIVATE TIMER
void setActive()
{
  active = true;
}


// SET MODE
// Is "set" switch pressed?
boolean getModeSwitch()
{
  // Assuming set switch is active low
  return( digitalRead( setSwitchPin ) == LOW );
}


// TEMPERATURE
// Reading temperature sensor
float readTemp( int pin, int sensType )
{
  // Temperature Sensor constants:
  //   0  LM60
  //   1  MAX6605
  //   2  TMP36
  int mVoltsAtRefTemp[] = { 424, 744, 750 };
  int refTempC[] = { 0, 0, 25 };
  float mVperDegC[] = { 6.25, 11.9, 10.0 };

  float mVolts = analogRead(vTempPin);

  return(mVolts);
}


// HYSTERESIS
// If not charged, call this method to wait until charged
void waitForCharge()
{
  isCharged = false;
  digitalWrite(chargeCap, HIGH);
  vCutCap = analogRead( vCutCapPin ) / 1024.0;
  vBatt = analogRead( vBattPin ) / 1024.0;
 
  while ( vCutCap < vRefStop )
  {
    delay(40);
    Serial.print("Battery Charge = ");
    Serial.print(vBatt);
    Serial.print("V, ");
    Serial.print("Capacitor Charge = ");
    Serial.print(vCutCap);
    Serial.println("V. Waiting for full capacitor charge...");
    Serial.flush();
    
    delay(5000);
    flashTimerLED( ledFlashTime, 1 );
    
    vCutCap = analogRead( vCutCapPin ) / 1024.0;
    vBatt = analogRead( vBattPin ) / 1024.0;
  }
  
  isCharged = true;
  digitalWrite(chargeCap, LOW);
  //digitalWrite(LEDPinCharge, HIGH);
}


// TROUBLESHOOTING
// If code is not working properly, run this to see if too much ram is being used
int freeRam() 
{
  extern int __heap_start, *__brkval; 
  int v; 
  return (int) &v - (__brkval == 0 ? (int) &__heap_start : (int) __brkval);
}

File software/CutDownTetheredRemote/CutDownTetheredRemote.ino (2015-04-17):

#include <EEPROM.h>

#include <MsTimer2.h>

/*
 * CutDownRemoteTemp
 *
 * Lou Nigra
 * Adler Planetarium - Far Horizons
 *
 * Brendan Batliner and Milan Shah
 * Illinois Mathematics and Science Academy - SIR Program
 * 
 * An interim design Upgraded for digital charging control, but
 * without the display and manual programming interface.
 *
 * Controls:
 *  Raw voltage tied to charger ON switch
 *  Programming mode when serial port is connected
 *  Timer activate/de-activate momentary contact switch (no longer used)
 *
 * Indicators:
 *  LED no blink: Charging => Programming mode inhibited.
 *  LED fast blink: Active => Timer is counting down.
 *  LED long Off: Standby => Waiting for programming window to open.
 *  LED single three flashes: Programming mode => Window open for "non-D"
 *                          input to enter programming mode.
 *
 *  The following sequence follows if a non-D character is entered while
 *  the window is open:
 *
 *  LED single six flashes: Parameter prompt: => Ready for parameter entry.
 *  LED three flashes: Confirmation: => Ready for y or n
 *
 * State Machine:
 *  standby -> WAITFORCHARGE
 *  WAITFORCHARGE
 *    -> GETTTY
 *  GETTTY
 *    (timeout) -> SLEEP
 *    (entries) -> active -> SLEEP
 *  SLEEP
 *      standby? => TTY
 *      active?  -> timerUpdate
 */
// General constants 
float vRef = 3.3;
int cutPin = 10;
int cutChgPin = 8;
float vChgLow = 4.45; //Hysteresis low
float vChgHigh = 4.55; //Hysteresis high
int vTempPin = 3;
int vBattPin = 2;
int pwrDnPin = 7;
//int cutChgDisablePin = 8;
float vBattRange = vRef * ( 39 + 82 ) / 39.0 ;
int vCutCapPin = 0;
float vCutCapRange = vRef * (51 + 51 ) / 51.0; //2.0;
//int vBackupCapPin = 2;
//float vBackupCapRange = vRef * 2.0;
int ledPin = 13;
int modePin = 3;
float timeOhFactor = 0.0996; //0.1213; //0.0333; //Empirical with 3 second activeSleepTime
int maxEepromAddr = 1023; //ATMega328
String dataValues = "2*(T+75)(C), vB*20(V), vC*20(V), Cut";
float vBatt;
float vCutCap;

// Variable declarations;
int cut;
int cutDelayMins;
int ttyPollTime;
int ttyWindowTimeSecs;
int standbySleepTime;
int activeSleepTime;
int sleepTime;
int sampleCount;
int sampleNum;
int sampleTime;
float cutTimerMins;
float maxAlt;
float maxRadius;
float center_lat;
float center_lon;
float vCharged;
boolean isCharged;
boolean ledState;
int ledFlashTime;
int dataSampleInterval;
int sensType;
boolean standby;
boolean active;
boolean sleep;
boolean chgEnable;
boolean cutActive;
boolean isCut;
int eepromAddr;

void setup()
{
  pinMode(cutPin, OUTPUT);
  pinMode(cutChgPin, OUTPUT);
  pinMode(ledPin, OUTPUT);
  pinMode(modePin, INPUT_PULLUP );
  pinMode(pwrDnPin, OUTPUT);
  //pinMode(cutChgDisablePin, OUTPUT);
  setCut( false );
  setCutChg( false );
  isCut = false;
  setLED( false );
  setPwrDown( true );
  sensType = 0; //LM60
  ttyPollTime = 6000; //ms
  ttyWindowTimeSecs = 10; //secs
  standbySleepTime = 30000; //ms
  activeSleepTime = 3000; //ms
  sampleTime = 60; //ms
  float temp = ( 1000.0 * sampleTime ) / ( 1.0 * activeSleepTime );
  sampleCount = (int)( 0.5 + temp);
  ledFlashTime = 10; //ms
  active = false;
  standby = true;
  sleepTime = activeSleepTime;
  cutDelayMins = 0;
  cutTimerMins = 0;
  sampleNum = 1;
  Serial.begin(9600);
  Serial.flush();
  isCharged = false;
  MsTimer2::set( 3000, timesUp );
  cutActive = false; // Flag to limit active cutdown to one interrupt cycle.
  isCut = false; // Flag to make sure only one cutdown command is recognized
  vCutCap = vCutCapRange * analogRead( vCutCapPin ) / 1024.0;
  vBatt = vBattRange * analogRead( vBattPin ) / 1024.0;
  vCharged = vChgLow;
  //waitForCharge();
  MsTimer2::start();
}

void loop() // run over and over again
{ 
  if ( !sleep ) {    
    setPwrDown( false );
    if ( isCharged ) {
      Serial.write('R');
    } else {
      Serial.write('W');
    }
    Serial.write('B');Serial.print(vBatt);;
    Serial.write('C');Serial.print(vCutCap);
    sleep = true;
    if ( !isCut ) cutActive = cutdownReceived();
    setCut( cutActive );
    if ( cutActive ) {
      cutActive = false;
      isCut = true;
    }
    Serial.flush();
    setPwrDown( true );
  }
}

void setPwrDown( boolean state ) {
  digitalWrite( pwrDnPin, state );
  if ( !state) delay(100); // Allow 100 ms for xBee to turn on.
}

void setCut( boolean state ) {
  digitalWrite( cutPin, state );
}

void setCutChg( boolean state ) {
  //digitalWrite( cutChgDisablePin, !state );
}

void timesUp() {
  charge();
  sleep = false;
}

boolean updateTimer() {
  cutTimerMins += ( ( 1 + timeOhFactor ) * activeSleepTime / 60000.0 );
  return( int(cutTimerMins) == cutDelayMins );
}

boolean cutdownReceived() {
  boolean isReceived = false;
  for (int i = 0; i < 10; i++) 
  {
    if (Serial.available() > 0)
    {
      int incomingByte = Serial.read();
      if (incomingByte == 'C')
      {
        isReceived = true;
        Serial.write('D');
      }
    }
    delay(30);
  }
  Serial.flush();
  return isReceived;
}

void setLED( boolean state ) {
  if ( state ) {
    digitalWrite( ledPin, HIGH );
  } else {
    digitalWrite( ledPin, LOW );
  }
}

void flashLED( int flashTime, int numFlashes ) {
  for ( int i = 0 ; i < numFlashes ; i++ ) {
    digitalWrite( ledPin, HIGH );
    delay( flashTime );
    digitalWrite( ledPin, LOW );
    delay(100);
  }
  
}

boolean isActive() {
  return( active );
}

void setActive() {
  active = true;
}

boolean isStandby() {
  return( standby );
}

boolean getModeSwitch() {
  // Mode switch is active low
  return( digitalRead( modePin ) == LOW );
}

float readTemp( int pin, int sensType ) {
  // Temperature Sensor constants:
  //   0  LM60
  //   1  MAX6605
  //   2  TMP36
  int mVoltsAtRefTemp[] = { 424, 744, 750 };
  int refTempC[] = { 0, 0, 25 };
  float mVperDegC[] = { 6.25, 11.9, 10.0 };

  int reading = analogRead(vTempPin);
  float mVolts = reading * vRef / 1.024;

  return( ( mVolts - mVoltsAtRefTemp[sensType] ) / 
            ( mVperDegC[sensType] ) + 
            refTempC[sensType]);
  
}

void charge() {
  vCutCap = vCutCapRange * analogRead( vCutCapPin ) / 1024.0;
  vBatt = vBattRange * analogRead( vBattPin ) / 1024.0;
  if ( vCutCap < vChgLow ) {
    setCharge( HIGH );
  }
  if ( vCutCap > vChgHigh )  {
    setCharge( LOW );
  }
  isCharged = vCutCap > vCharged;
}

boolean setCharge( boolean charge ) {
  digitalWrite( cutChgPin, charge );
}

int freeRam() 
{
  extern int __heap_start, *__brkval; 
  int v; 
  return (int) &v - (__brkval == 0 ? (int) &__heap_start : (int) __brkval); 
}

  

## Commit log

2014-07-12 Initial commit.
    [ChargerTimer.brd, ChargerTimer.sch, ChargerTimer_V3hack.brd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]
2014-07-19 Remote: Added Start/Stop Switch, Set Switch, Vars Switch, Timer LED, Set LED, and Vars LEDs; UP/DOWN Switches not yet implemented; Not enough pins for all elements
2014-07-19 Remote: Added all LEDs and Switches, Removed large portions of old code. Documentation: Edited and updated main README and CutDownRemote documentation
2014-08-24 Initial schematic
    [CutDown2.sch]
2014-08-30 Kelli+Rachel upcounter display proto
    [CutDown2_BreadBoard.sch]
2014-08-31 Rachael: Added initial skeleton of Hysteresis for capacitor charging; cleaned up variables; removed standby variable in favor of using active to tell whether Remote is in standby.
2015-04-17 New CutDown prototype initially for tethered parasail drop tests
2015-04-17 Fixed green light function
    Green light now turns off on base when disconnected from remote.
    [CutDownBaseTemp.ino]

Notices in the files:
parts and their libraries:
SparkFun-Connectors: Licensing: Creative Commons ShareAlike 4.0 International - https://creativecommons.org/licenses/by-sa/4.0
